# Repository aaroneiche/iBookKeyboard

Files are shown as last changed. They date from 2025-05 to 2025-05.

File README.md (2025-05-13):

# iBook Keyboard & Trackpad adapter

This board is a controller to drive a keyboard and trackpad on an Apple Clamshell iBook G3 - the original iBooks.

### Huh?

Yeah, I'm in the process of making an iBook chassis into a modern computer, and this is the first step. You can find more information (and progress) on this project at the [project page on my website](https://aaroneiche.com/projects/pibook).

### What are the JST connectors for?
Eventually I hope to integrate the controls for the Power button, trackpad button, and the lid-closed sensor (a magnetic *reed switch*). I haven't gotten to that yet, so for right now, they're just connectors that go to GPIO on the RP2040.

The RGB out is something where I'm hoping to support RGB LEDs to pass through the keyboard for fun. This is a "bells and whistles" type thing, and might not ever get addressed.

### Can I use it?
Yes, you can. But please be aware that I haven't finalized the design and I'm not sure that it'll work 100% yet. Also, the firmware is in an incomplete state (and not included in this repo yet), so *caveat emptor*. That said, if you have questions feel free to send me a message. I'm happy to help where I can.

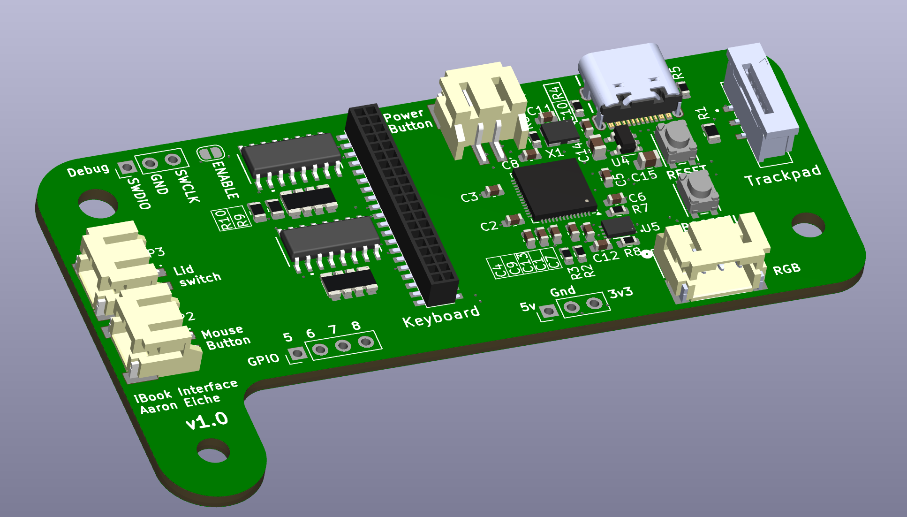
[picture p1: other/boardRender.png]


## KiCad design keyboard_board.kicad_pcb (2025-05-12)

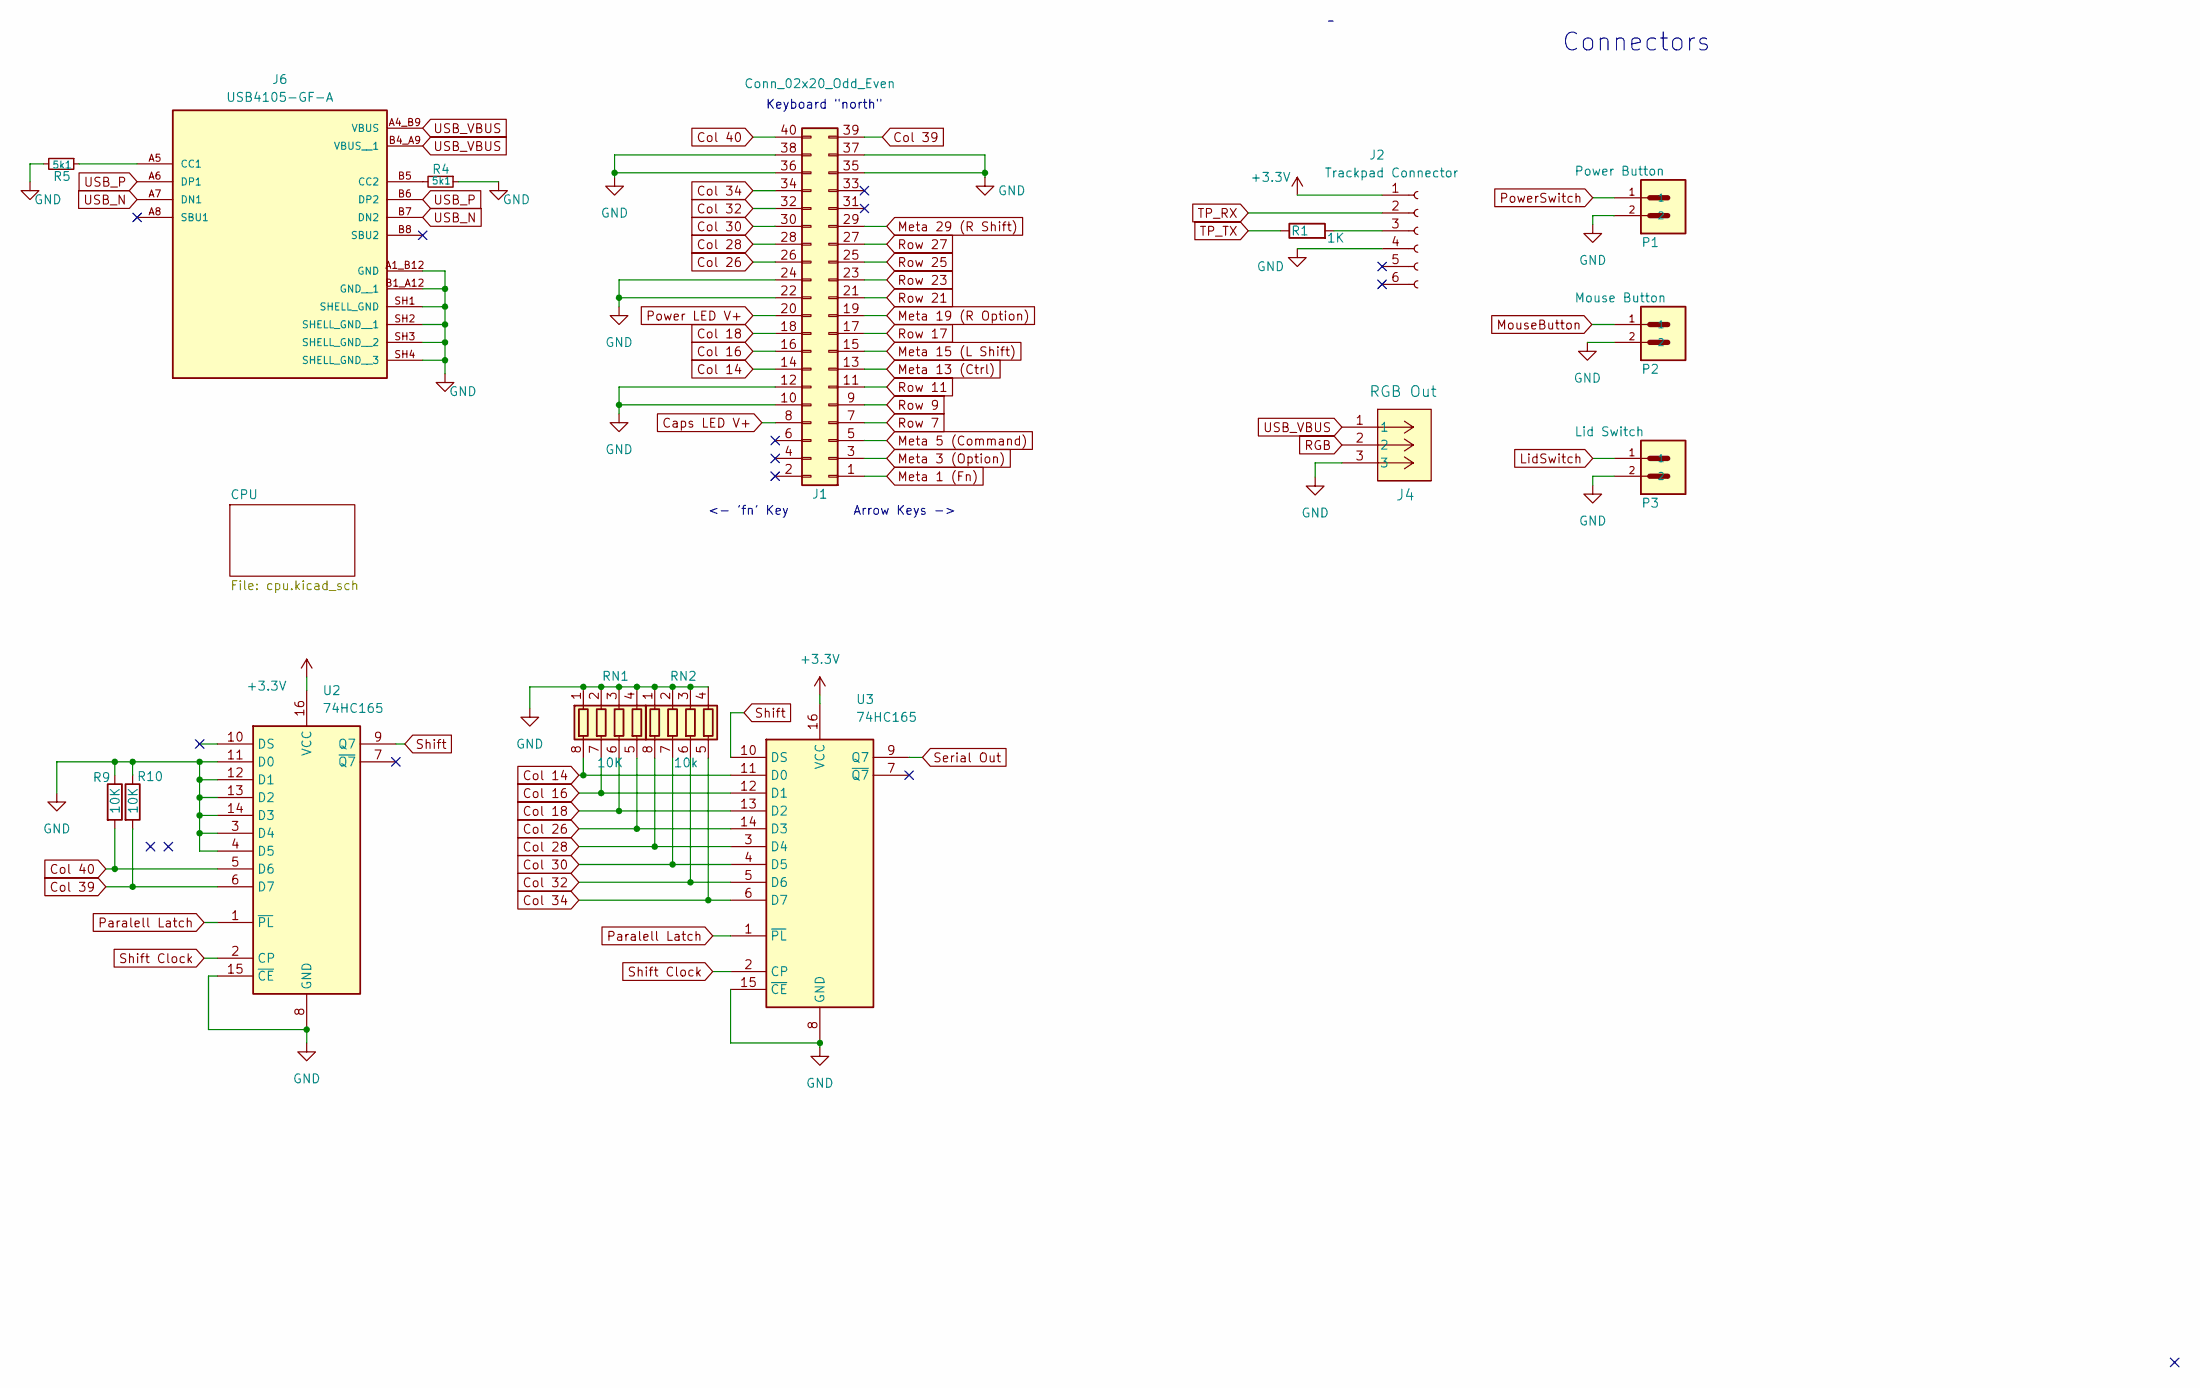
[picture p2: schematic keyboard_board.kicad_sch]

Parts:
J1: Conn_02x20_Odd_Even; 2x20_1.27_DIP_F
J2: Trackpad Connector; AMPHENOL_SFW6S-2STE1LF
J4: RGB Out; CONN3_S3B-PH_JST
J6: USB4105-GF-A; GCT_USB4105-GF-A; PARTREV B4
P1: Power Button; JST_S2B-PH-SM4-TB
P2: Mouse Button; JST_S2B-PH-SM4-TB
P3: Lid Switch; JST_S2B-PH-SM4-TB
R1: 1K; R_0805_2012Metric
R4, R5: 5k1; R_0603_1608Metric
R9, R10: 10K; R_0805_2012Metric
RN1: 10K; R_Array_Convex_4x1206
RN2: 10k; R_Array_Convex_4x1206
U2, U3: 74HC165; D16-L

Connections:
+3.3V: J2.1, U2.16 (VCC), U3.16 (VCC); also elsewhere on the board
Caps LED V+: J1.8; also elsewhere on the board
Col 14: J1.14, RN1.8 (R1.2), U3.11 (D0)
Col 16: J1.16, RN1.7 (R2.2), U3.12 (D1)
Col 18: J1.18, RN1.6 (R3.2), U3.13 (D2)
Col 26: J1.26, RN1.5 (R4.2), U3.14 (D3)
Col 28: J1.28, RN2.8 (R1.2), U3.3 (D4)
Col 30: J1.30, RN2.7 (R2.2), U3.4 (D5)
Col 32: J1.32, RN2.6 (R3.2), U3.5 (D6)
Col 34: J1.34, RN2.5 (R4.2), U3.6 (D7)
Col 39: J1.39, R10.2, U2.6 (D7)
Col 40: J1.40, R9.2, U2.5 (D6)
GND: J1.10, J1.12, J1.22, J1.24, J1.35, J1.36, J1.37, J1.38, J2.4, J4.3, J6.A1_B12 (GND), J6.B1_A12 (GND__1), J6.SH1 (SHELL_GND), J6.SH2 (SHELL_GND__1), J6.SH3 (SHELL_GND__2), J6.SH4 (SHELL_GND__3), P1.2, P2.2, P3.2, R4.1, R5.2, R9.1, R10.1, RN1.1 (R1.1), RN1.2 (R2.1), RN1.3 (R3.1), RN1.4 (R4.1), RN2.1 (R1.1), RN2.2 (R2.1), RN2.3 (R3.1), RN2.4 (R4.1), U2.3 (D4), U2.4 (D5), U2.8 (GND), U2.11 (D0), U2.12 (D1), U2.13 (D2), U2.14 (D3), U2.15 (~CE), U3.8 (GND), U3.15 (~CE); also elsewhere on the board
LidSwitch: P3.1; also elsewhere on the board
Meta 1 (Fn): J1.1; also elsewhere on the board
Meta 3 (Option): J1.3; also elsewhere on the board
Meta 5 (Command): J1.5; also elsewhere on the board
Meta 13 (Ctrl): J1.13; also elsewhere on the board
Meta 15 (L Shift): J1.15; also elsewhere on the board
Meta 19 (R Option): J1.19; also elsewhere on the board
Meta 29 (R Shift): J1.29; also elsewhere on the board
MouseButton: P2.1; also elsewhere on the board
unnamed: J2.3, R1.2
unnamed: J6.A5 (CC1), R5.1
unnamed: J6.B5 (CC2), R4.2
Paralell Latch: U2.1 (~PL), U3.1 (~PL); also elsewhere on the board
Power LED V+: J1.20; also elsewhere on the board
PowerSwitch: P1.1; also elsewhere on the board
RGB: J4.2; also elsewhere on the board
Row 7: J1.7; also elsewhere on the board
Row 9: J1.9; also elsewhere on the board
Row 11: J1.11; also elsewhere on the board
Row 17: J1.17; also elsewhere on the board
Row 21: J1.21; also elsewhere on the board
Row 23: J1.23; also elsewhere on the board
Row 25: J1.25; also elsewhere on the board
Row 27: J1.27; also elsewhere on the board
Serial Out: U3.9 (Q7); also elsewhere on the board
Shift: U2.9 (Q7), U3.10 (DS)
Shift Clock: U2.2 (CP), U3.2 (CP); also elsewhere on the board
TP_RX: J2.2; also elsewhere on the board
TP_TX: R1.1; also elsewhere on the board
USB_N: J6.A7 (DN1), J6.B7 (DN2); also elsewhere on the board
USB_P: J6.A6 (DP1), J6.B6 (DP2); also elsewhere on the board
USB_VBUS: J4.1, J6.A4_B9 (VBUS), J6.B4_A9 (VBUS__1); also elsewhere on the board

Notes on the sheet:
<- 'fn' Key
Connectors
Arrow Keys ->
Keyboard "north"

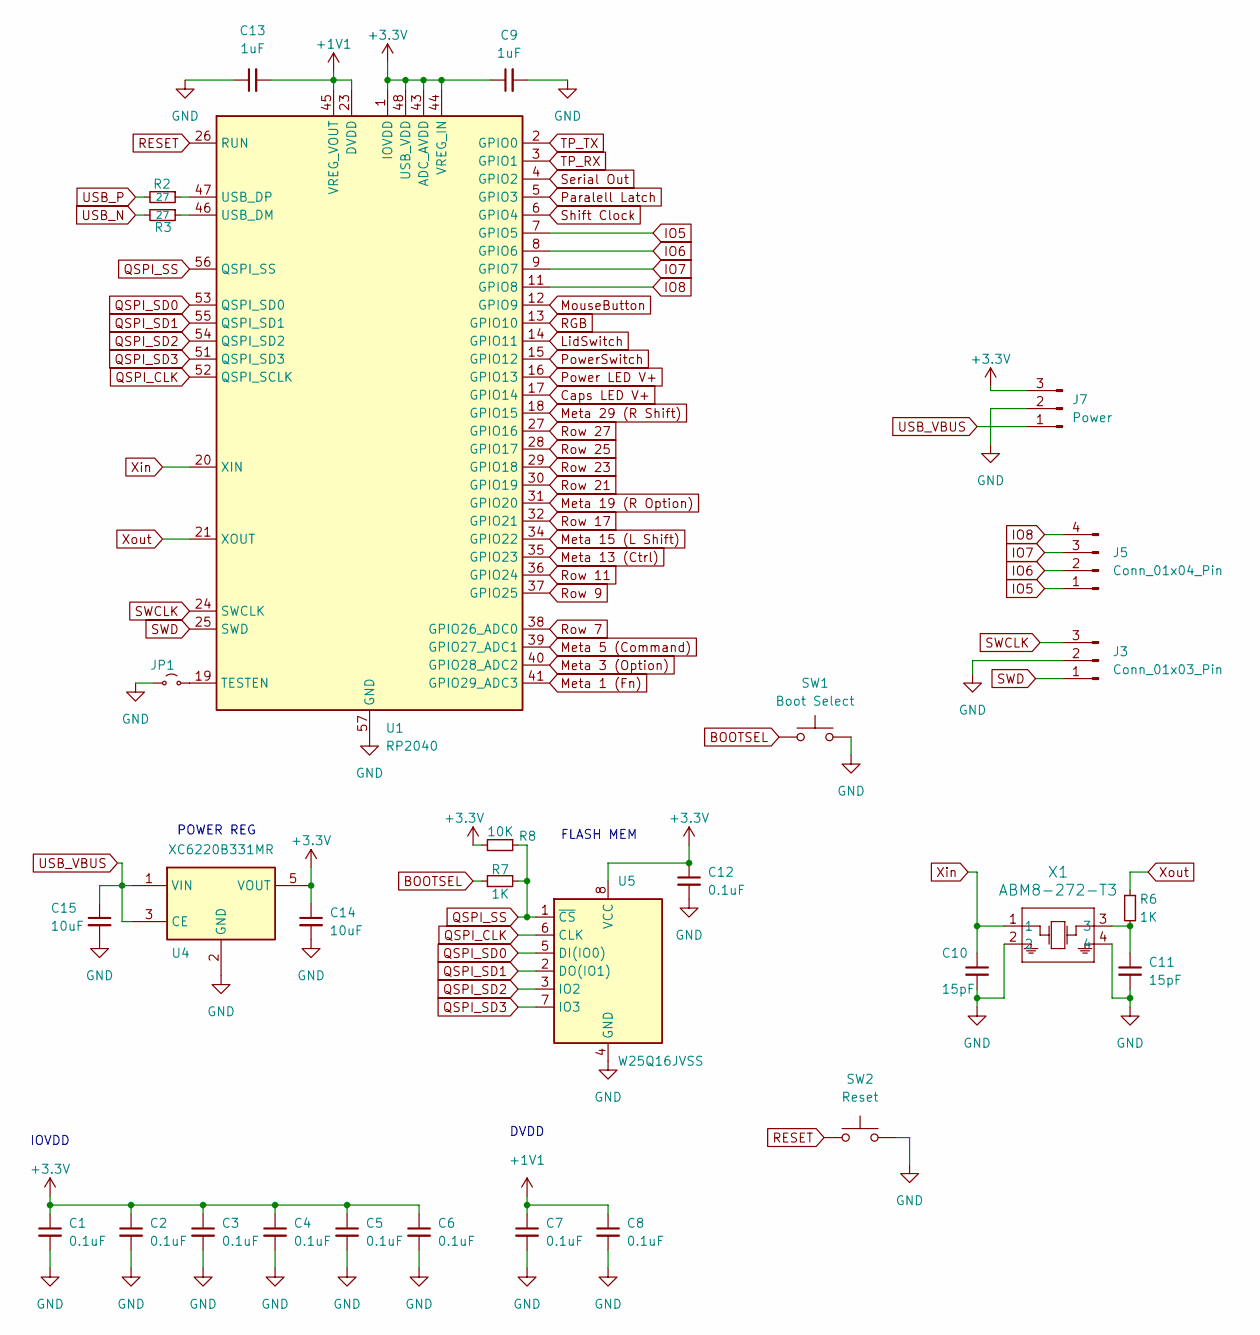
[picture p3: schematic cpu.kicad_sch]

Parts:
C1, C2, C3, C4, C5, C6, C7, C8, C12: 0.1uF; C_0603_1608Metric
C9, C13: 1uF; C_0603_1608Metric
C10, C11: 15pF; C_0603_1608Metric
C14, C15: 10uF; C_0805_2012Metric
J3: Conn_01x03_Pin; PinHeader_1x03_P2.54mm_Vertical
J5: Conn_01x04_Pin; PinHeader_1x04_P2.54mm_Vertical
J7: Power; PinHeader_1x03_P2.54mm_Vertical
JP1: Jumper_2_Small_Open; SolderJumper-2_P1.3mm_Open_RoundedPad1.0x1.5mm
R2, R3: 27; R_0603_1608Metric
R6, R7: 1K; R_0603_1608Metric
R8: 10K; R_0603_1608Metric
SW1: Boot Select; SW4_PTS815 SJM 250 SMTR LFS_CNK
SW2: Reset; SW4_PTS815 SJM 250 SMTR LFS_CNK
U1: RP2040; QFN-56-1EP_7x7mm_P0.4mm_EP3.2x3.2mm; Digikey P/N 2648-SC0914(13)CT-ND
U4: XC6220B331MR; SOT-23-5; Digikey P/N 296-50414-1-ND
U5: W25Q16JVSS; USON-8_UX_2x3x0p6_WIN; Digikey P/N 256-W25Q16JVUXIQTRCT-ND
X1: ABM8-272-T3; ABM8-272-T3_ABR

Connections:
+1V1: C7.1, C8.1, C13.2, U1.23 (DVDD), U1.45 (VREG_VOUT), U1.50 (DVDD)
+3.3V: C1.1, C2.1, C3.1, C4.1, C5.1, C6.1, C9.1, C12.1, C14.1, J7.3, R8.2, U1.1 (IOVDD), U1.10 (IOVDD), U1.22 (IOVDD), U1.33 (IOVDD), U1.42 (IOVDD), U1.43 (ADC_AVDD), U1.44 (VREG_IN), U1.48 (USB_VDD), U1.49 (IOVDD), U4.5 (VOUT), U5.8 (VCC); also elsewhere on the board
BOOTSEL: R7.1, SW1.1
Caps LED V+: U1.17 (GPIO14); also elsewhere on the board
GND: C1.2, C2.2, C3.2, C4.2, C5.2, C6.2, C7.2, C8.2, C9.2, C10.2, C11.2, C12.2, C13.1, C14.2, C15.2, J3.2, J7.2, JP1.1 (A), SW1.2, SW2.2, U1.57 (GND), U4.2 (GND), U5.4 (GND), X1.2, X1.4; also elsewhere on the board
IO5: J5.1, U1.7 (GPIO5)
IO6: J5.2, U1.8 (GPIO6)
IO7: J5.3, U1.9 (GPIO7)
IO8: J5.4, U1.11 (GPIO8)
LidSwitch: U1.14 (GPIO11); also elsewhere on the board
Meta 1 (Fn): U1.41 (GPIO29_ADC3); also elsewhere on the board
Meta 3 (Option): U1.40 (GPIO28_ADC2); also elsewhere on the board
Meta 5 (Command): U1.39 (GPIO27_ADC1); also elsewhere on the board
Meta 13 (Ctrl): U1.35 (GPIO23); also elsewhere on the board
Meta 15 (L Shift): U1.34 (GPIO22); also elsewhere on the board
Meta 19 (R Option): U1.31 (GPIO20); also elsewhere on the board
Meta 29 (R Shift): U1.18 (GPIO15); also elsewhere on the board
MouseButton: U1.12 (GPIO9); also elsewhere on the board
unnamed: C11.1, R6.2, X1.3
unnamed: JP1.2 (B), U1.19 (TESTEN)
unnamed: R3.1, U1.46 (USB_DM)
unnamed: R2.1, U1.47 (USB_DP)
Paralell Latch: U1.5 (GPIO3); also elsewhere on the board
Power LED V+: U1.16 (GPIO13); also elsewhere on the board
PowerSwitch: U1.15 (GPIO12); also elsewhere on the board
QSPI_CLK: U1.52 (QSPI_SCLK), U5.6 (CLK)
QSPI_SD0: U1.53 (QSPI_SD0), U5.5 (DI(IO0))
QSPI_SD1: U1.55 (QSPI_SD1), U5.2 (DO(IO1))
QSPI_SD2: U1.54 (QSPI_SD2), U5.3 (IO2)
QSPI_SD3: U1.51 (QSPI_SD3), U5.7 (IO3)
QSPI_SS: R7.2, R8.1, U1.56 (QSPI_SS), U5.1 (~CS)
RESET: SW2.1, U1.26 (RUN)
RGB: U1.13 (GPIO10); also elsewhere on the board
Row 7: U1.38 (GPIO26_ADC0); also elsewhere on the board
Row 9: U1.37 (GPIO25); also elsewhere on the board
Row 11: U1.36 (GPIO24); also elsewhere on the board
Row 17: U1.32 (GPIO21); also elsewhere on the board
Row 21: U1.30 (GPIO19); also elsewhere on the board
Row 23: U1.29 (GPIO18); also elsewhere on the board
Row 25: U1.28 (GPIO17); also elsewhere on the board
Row 27: U1.27 (GPIO16); also elsewhere on the board
SWCLK: J3.3, U1.24 (SWCLK)
SWD: J3.1, U1.25 (SWD)
Serial Out: U1.4 (GPIO2); also elsewhere on the board
Shift Clock: U1.6 (GPIO4); also elsewhere on the board
TP_RX: U1.3 (GPIO1); also elsewhere on the board
TP_TX: U1.2 (GPIO0); also elsewhere on the board
USB_N: R3.2; also elsewhere on the board
USB_P: R2.2; also elsewhere on the board
USB_VBUS: C15.1, J7.1, U4.1 (VIN), U4.3 (CE); also elsewhere on the board
Xin: C10.1, U1.20 (XIN), X1.1
Xout: R6.1, U1.21 (XOUT)

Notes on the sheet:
FLASH MEM
IOVDD
POWER REG
DVDD

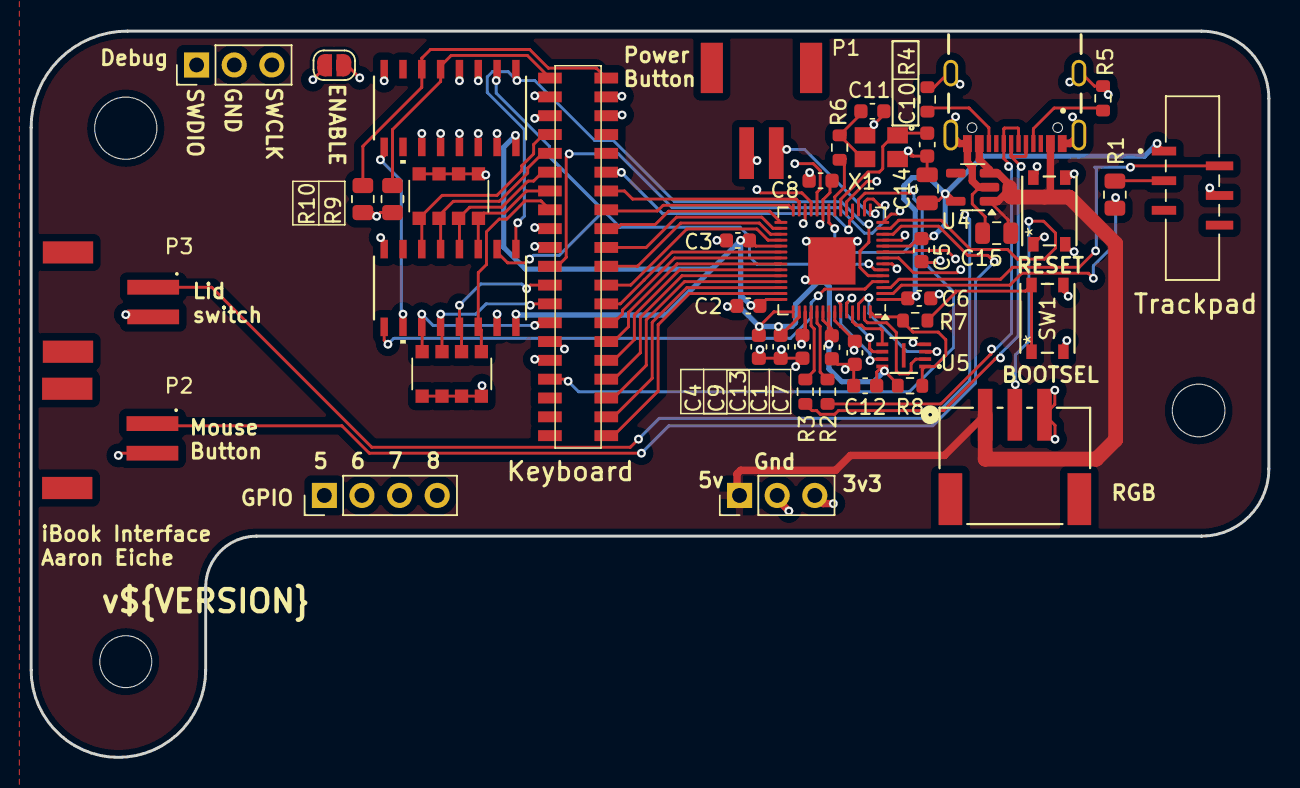
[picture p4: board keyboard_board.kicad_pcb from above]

Board: 4 copper layers, 83.5 x 49.0 mm, 46 parts (0 on the bottom side), 66 nets.

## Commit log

2025-03-11 Initial commit - laid out board.
    [keyboard_board.kicad_pcb, keyboard_board.kicad_sch]
2025-03-12 -Changes USB labels to support differential pair - Does some major layout changes.
    [keyboard_board.kicad_pcb, keyboard_board.kicad_sch]
2025-03-13 Adds Power input 2-pin JST PH. Adds RGB output Adds Power Button input
    [keyboard_board.kicad_pcb, keyboard_board.kicad_sch]
2025-03-14 Adds Gerber files.
    [keyboard_board-B_Cu.gbr, keyboard_board-B_Mask.gbr, keyboard_board-B_Paste.gbr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]
2025-03-19 Completes Pico version
    [keyboard_board.kicad_pcb, keyboard_board.kicad_sch]
2025-03-19 Updates to Pico version
    [keyboard_board.kicad_pcb, keyboard_board.kicad_sch]
2025-03-19 'gebers directory' removal
    [keyboard_board-B_Cu.gbr, keyboard_board-B_Mask.gbr, keyboard_board-B_Paste.gbr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]
2025-03-21 Reworks Pico-based into discrete components
    [cpu.kicad_sch, keyboard_board.kicad_pcb, keyboard_board.kicad_sch]
2025-05-12 prod version, I think
    [connectors.kicad_sch, cpu.kicad_sch, keyboard_board.kicad_pcb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]
